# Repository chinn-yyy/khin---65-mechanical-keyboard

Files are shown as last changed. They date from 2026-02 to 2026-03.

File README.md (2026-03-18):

# khin---65-mechanical-keyboard
This keyboard was designed for productivity for the Blueprint club ran by HackClub. It features a 66 key layout with 2 programmable macro keys. I chose the MMD Fairy Linear switches for this project. Not only do they sound amazing, they also match my vibe; transparent. Additionally, I decided to use some random AliExpress screw-in stabilizers that are also, you guessed it, transparent! 

My keyboard isn't just a keyboard with keys. It also features a big, bright, 0.91 inch OLED display that can display the last key you pressed, a fun animation, etc. Not only does it have an OLED it also has 68 addressable LED's. One for each key. These can be any color and any pattern.

On the firmware side of things, my keyboard is being ran by QMK open source firmware on a Raspberry Pi Pico. QMK is specifically designed for keyboards, and not only is it easy to use but it also has tons of features. 

Make sure to look at my Blueprint page to see the journal and the process it took to build this. Here is the link: https://blueprint.hackclub.com/projects/11738

Here are some photos of the finished product:

  Fully Assembled (CAD):
  


  Schematic:


  PCB Editor:


  CAD:
  




[tableConvert.com_irgoez.md](https://github.com/user-attachments/files/25429461/tableConvert.com_irgoez.md)
| Name: | Description: | Price: (each) | Shipping Price: | Quanity: | Manufacturer: | Total Price (with tax + shipping): | URL: |
|---|---|---|---|---|---|---|---|
| Raspberry Pi Pico w/ Headers | 40 pin RP2040 based MCU, the brains for the keyboard. (not the offical one, proceed with caution) | $3.41 | $0.00 | 1 | AliExpress | $3.94 | https://www.aliexpress.us/item/3256805941727857.html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 |
| V2 PCB Mount Screw-in Stabilizers | Keyboard stabilizers, allows the space, shift etc. to not collapse. | $5.27 | $0.00 | 1 | AliExpress | $6.08 | https://www.aliexpress.us/item/3256807050530252.html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 |
| MMD Fairy Switch Linear | Clear keyboard switches, buttons. Pack of 70. | $32.57 | $0.00 | 1 | AliExpress | $37.59 | https://www.aliexpress.us/item/3256805623892710.html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 |
| 1N4148 Switching Diode | Used in the keyboard matrix to prevent ghosting. Pack of 50. | $1.23 | $0.00 | 2 | AliExpress | $2.84 | https://www.aliexpress.us/item/3256806058794623.html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 |
| SK6812 MINI-E RGB | Addressable LED's for the keyboard. Pack of 100. | $6.03 | $0.00 | 1 | AliExpress | $6.96 | https://www.aliexpress.us/item/3256805007401420.html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 |
| 0.91 inch OLED | 0.91 inch, 128x32, SSD1306, I2C, OLED display. (already have) | $1.97 | $0.00 | 1 | AliExpress | $0.00 | https://www.aliexpress.us/item/3256805114690528.html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 |
| Custom PCB | Custom printed circuit board, the foundation. (pack of 5) | $17.60 | $12.97 | 1 | JLCPCB | $33.28 | https://jlcpcb.com/ |
| TOTAL: | | | | | | $91.75 | Link to Google Spreadsheet: https://docs.google.com/spreadsheets/d/17dnJcXFBqe7aWQwjPS5lmQD_NSss1hXRMHxMUS2wsAg/edit?usp=sharing |

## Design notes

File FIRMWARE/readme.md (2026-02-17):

# khin

khin

*65% mechanical keyboard running QMK firmware on a Raspberry Pi Pico with LED's, an OLED display, and 2 macro keys.*

* Keyboard Maintainer: [chinnyyy.](https://github.com/chinnyyy.)
* Hardware Supported: *Raspberry Pi Pico, custom PCB, Durock ice king switches*
* Hardware Availability: *https://github.com/chinn-yyy/khin---65-mechanical-keyboard*

Make example for this keyboard (after setting up your build environment):

    make khin:default

Flashing example for this keyboard:

    make khin:default:flash

See the [build environment setup](https://docs.qmk.fm/#/getting_started_build_tools) and the [make instructions](https://docs.qmk.fm/#/getting_started_make_guide) for more information. Brand new to QMK? Start with our [Complete Newbs Guide](https://docs.qmk.fm/#/newbs).

## Bootloader

Enter the bootloader in 3 ways:

* **Bootmagic reset**: Hold down the key at (0,0) in the matrix (usually the top left key or Escape) and plug in the keyboard
* **Physical reset button**: Briefly press the button on the back of the PCB - some may have pads you must short instead
* **Keycode in layout**: Press the key mapped to `QK_BOOT` if it is available
*

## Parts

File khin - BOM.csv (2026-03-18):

Name: | Description: | Price: (each) | Shipping Price: | Quanity: | Manufacturer: | Total Price (with tax + shipping): | URL:
Raspberry Pi Pico w/ Headers | 40 pin RP2040 based MCU, the brains for the keyboard. (not the offical one, proceed with caution) | $3.41 | $0.00 | 1 | AliExpress | $3.94 | https://www.aliexpress.us/item/3256805941727857.html?mp=1
V2 PCB Mount Screw-in Stabilizers | Keyboard stabilizers, allows the space, shift etc. to not collapse. | $5.27 | $0.00 | 1 | AliExpress | $6.08 | https://www.aliexpress.us/item/3256807050530252.html?mp=1
MMD Fairy Switch Tactile | Clear keyboard switches, buttons. Pack of 70. | $23.23 | $0.00 | 1 | AliExpress | $26.81 | https://www.aliexpress.us/item/3256805876055680.html?curPageLogUid=Gu2HeTS3mv6v
1N4148 Switching Diode | Used in the keyboard matrix to prevent ghosting. Pack of 50. | $1.23 | $0.00 | 2 | AliExpress | $2.84 | https://www.aliexpress.us/item/3256806058794623.html?mp=1
SK6812 MINI-E RGB | Addressable LED's for the keyboard. Pack of 100. | $6.03 | $0.00 | 1 | AliExpress | $6.96 | https://www.aliexpress.us/item/3256805007401420.html?mp=1
0.91 inch OLED | 0.91 inch, 128x32, SSD1306, I2C, OLED display. (already have) | $1.97 | $0.00 | 1 | AliExpress | $2.27 | https://www.aliexpress.us/item/3256805114690528.html?curPageLogUid=xd4wKAHaNW7A
Custom PCB | Custom printed circuit board, the foundation. (pack of 5) | $17.60 | $12.97 | 1 | JLCPCB | $33.28 | https://jlcpcb.com/
TOTAL: |  |  |  |  |  | $82.18 | Link to Google Spreadsheet: https://docs.google.com/spreadsheets/d/17dnJcXFBqe7aWQwjPS5lmQD_NSss1hXRMHxMUS2wsAg/edit?usp=sharing

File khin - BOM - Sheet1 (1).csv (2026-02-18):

Name: | Description: | Price: (each) | Shipping Price: | Quanity: | Manufacturer: | Total Price (with tax + shipping): | URL:
Raspberry Pi Pico w/ Headers | 40 pin RP2040 based MCU, the brains for the keyboard. | $5.00 | $0.00 | 1 | Vilros | $5.00 | https://vilros.com/products/raspberry-pi-pico?variant=41213088825438
GATERON PC Screw in Crystal Stabilizer | Keyboard stabilizers, allows the space, shift etc. to not collapse. | $11.99 | $0.00 | 1 | Amazon | $13.84 | https://www.amazon.com/gp/product/B0BZYK3X1S/ref=ox_sc_act_title_2?smid=A3EQZH47A6MSSO&psc=1
DUROCK Ice King Linear Switches | "Thocky," clear keyboard switches, buttons. Pack of 70. | $36.99 | $0.00 | 1 | Amazon | $42.69 | https://www.amazon.com/gp/product/B0CTH8VFJW/ref=ox_sc_act_image_1?smid=A1G6HFHDKP9H5J&th=1
1N4148 Switching Diode | Used in the keyboard matrix to prevent ghosting. Pack of 50. | $1.23 | $1.99 | 2 | AliExpress | $4.83 | https://www.aliexpress.us/item/3256806058794623.html?mp=1
SK6812 MINI-E RGB | Addressable LED's for the keyboard. Pack of 100. | $6.03 | $0.00* | 1 | AliExpress | $6.96 | https://www.aliexpress.us/item/3256805007401420.html?mp=1
0.91 inch OLED | 0.91 inch, 128x32, SSD1306, I2C, OLED display. (already have) | $1.97 | $0.00 | 1 | AliExpress | $0.00 | https://www.aliexpress.us/item/3256805114690528.html?curPageLogUid=xd4wKAHaNW7A
Custom PCB | Custom printed circuit board, the foundation. (pack of 5) | $17.60 | $12.97 | 1 | JLCPCB | $33.28 | https://jlcpcb.com/
TOTAL: |  |  | *Ships with switching diode |  |  | $106.59 | Link to Google Spreadsheet: https://docs.google.com/spreadsheets/d/17dnJcXFBqe7aWQwjPS5lmQD_NSss1hXRMHxMUS2wsAg/edit?usp=sharing

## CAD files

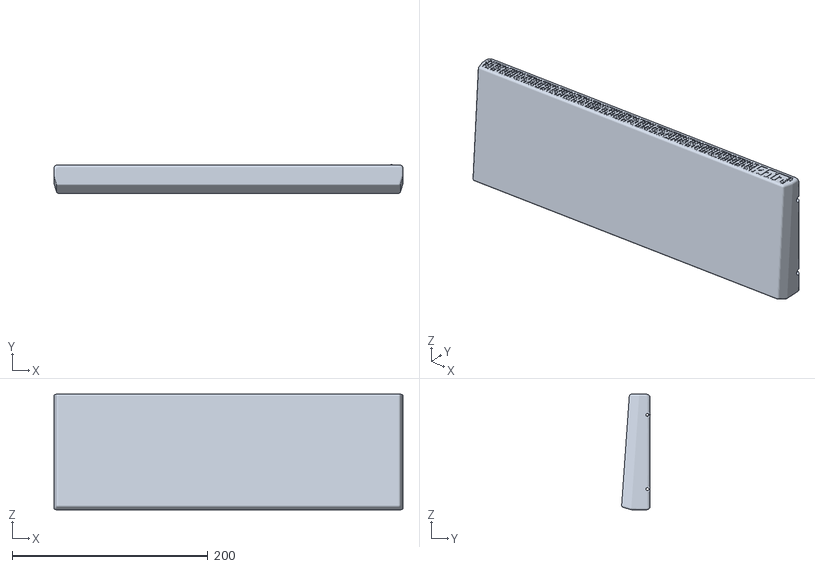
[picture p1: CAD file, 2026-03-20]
CAD/khin - 65% mechanical keyboard BASE.stl
356.5 x 29.4 x 118.0

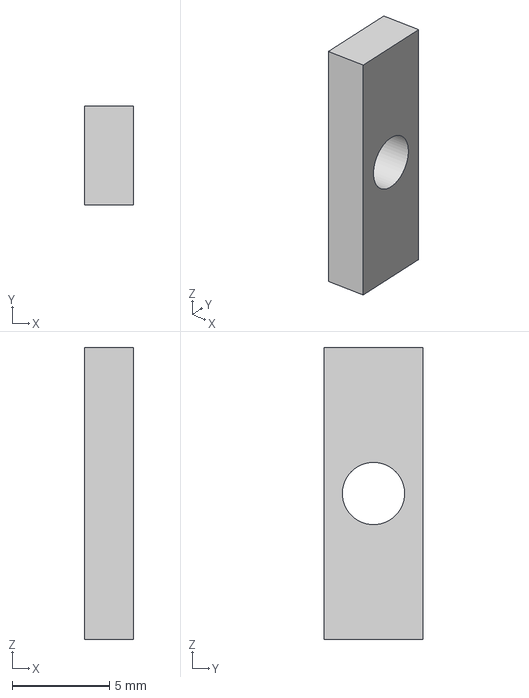
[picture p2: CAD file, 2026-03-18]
CAD/khin - 65% mechanical keyboard CLAMP.step
2.50 x 5.09 x 15.0 mm

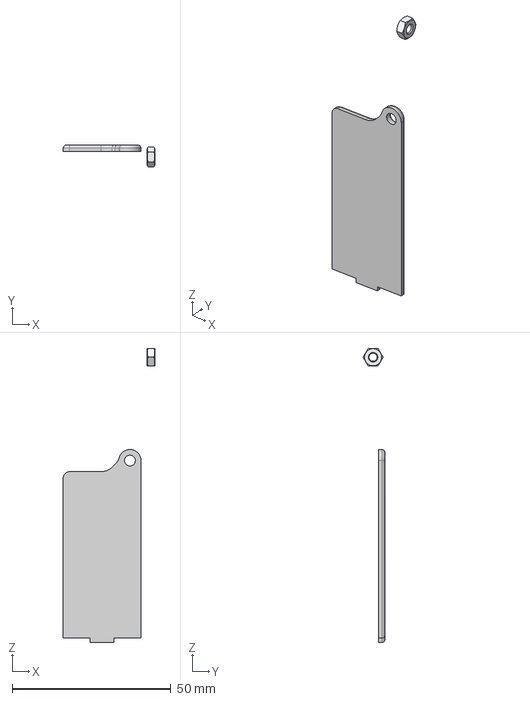
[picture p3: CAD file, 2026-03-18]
CAD/khin - 65% mechanical keyboard PI COVER.step
28.9 x 6.93 x 92.7 mm

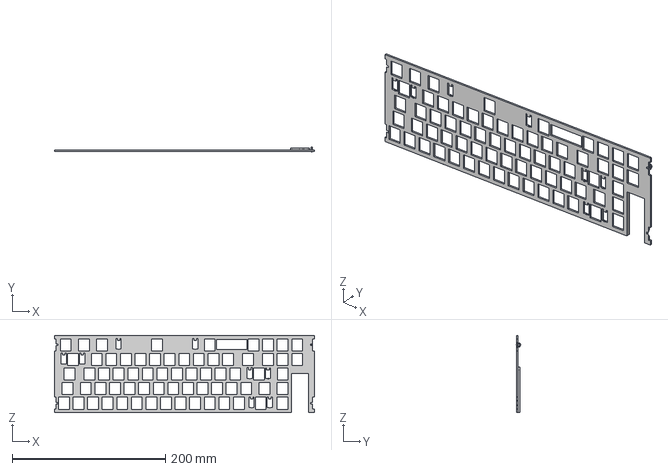
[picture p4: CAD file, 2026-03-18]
CAD/khin - 65% mechanical keyboard COVER.step
339.7 x 6.35 x 101.2 mm

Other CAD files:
CAD/khin - 65% mechanical keyboard CLAMP.stl
CAD/khin - 65% mechanical keyboard COVER.stl
CAD/khin - 65% mechanical keyboard PI COVER.stl
CAD/khin - 65% mechanical keyboardMAIN-FUSION.f3z

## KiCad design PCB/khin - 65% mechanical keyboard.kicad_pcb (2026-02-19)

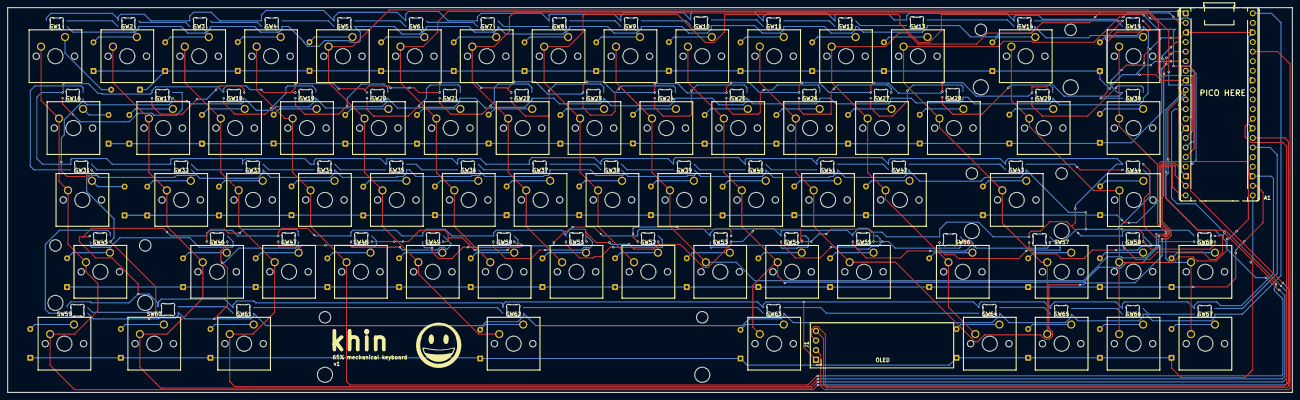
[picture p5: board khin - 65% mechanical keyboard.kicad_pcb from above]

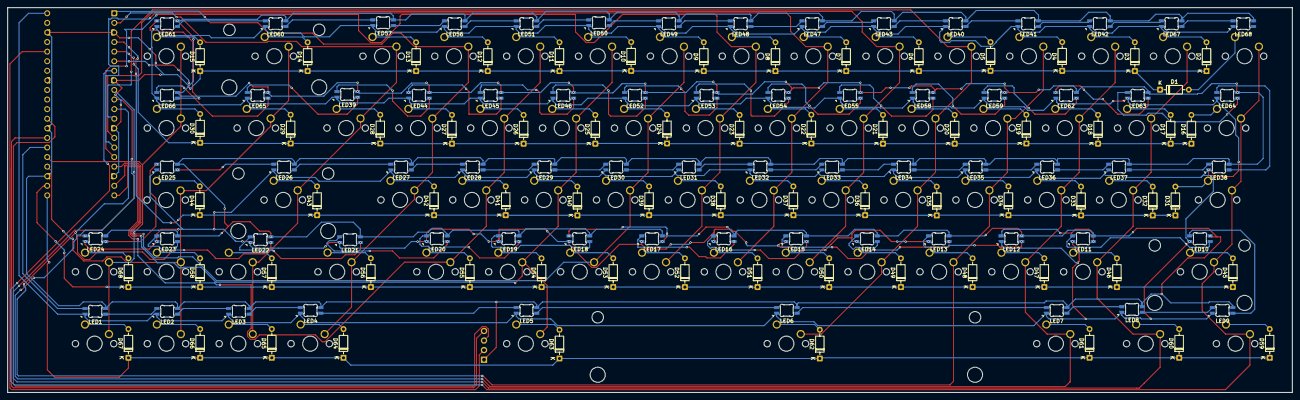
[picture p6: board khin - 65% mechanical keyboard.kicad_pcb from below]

Board: 2 copper layers, 340.5 x 102.0 mm, 206 parts (136 on the bottom side), 161 nets.

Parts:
A1: RaspberryPi_Pico; RaspberryPi_Pico_Common_THT
D1, D2, D3, D4, D5, D6, D7, D8, D9, D10, D11, D12, D13, D14, D15, D16, D17, D18, D19, D20, D21, D22, D23, D24, D25, D26, D27, D28, D29, D30, D31, D32, D33, D34, D35, D36, D37, D38, D39, D40, D41, D42, D43, D44, D45, D46, D47, D48, D49, D50, D51, D52, D53, D54, D55, D56, D57, D58, D59, D60, D61, D62, D63, D64, D65, D66, D67, D68: 1N4148; D_DO-35_SOD27_P7.62mm_Horizontal
J1: Conn_01x04_Pin; OLED_0.91_128x323D
LED1, LED2, LED3, LED4, LED5, LED6, LED7, LED8, LED9, LED10, LED11, LED12, LED13, LED14, LED15, LED16, LED17, LED18, LED19, LED20, LED21, LED22, LED23, LED24, LED25, LED26, LED27, LED28, LED29, LED30, LED31, LED32, LED33, LED34, LED35, LED36, LED37, LED38, LED39, LED40, LED41, LED42, LED43, LED44, LED45, LED46, LED47, LED48, LED49, LED50, LED51, LED52, LED53, LED54, LED55, LED56, LED57, LED58, LED59, LED60, LED61, LED62, LED63, LED64, LED65, LED66, LED67, LED68: MX_SK6812MINI-E; LED_6028R
SW1: SW_Push-ESC; SW_Cherry_MX_1.00u_PCB3D
SW2: SW_Push-1; SW_Cherry_MX_1.00u_PCB3D
SW3: SW_Push-2; SW_Cherry_MX_1.00u_PCB3D
SW4: SW_Push-3; SW_Cherry_MX_1.00u_PCB3D
SW5: SW_Push-4; SW_Cherry_MX_1.00u_PCB3D
SW6: SW_Push-5; SW_Cherry_MX_1.00u_PCB3D
SW7: SW_Push-6; SW_Cherry_MX_1.00u_PCB3D
SW8: SW_Push-7; SW_Cherry_MX_1.00u_PCB3D
SW9: SW_Push-8; SW_Cherry_MX_1.00u_PCB3D
SW10: SW_Push-9; SW_Cherry_MX_1.00u_PCB3D
SW11: SW_Push-0; SW_Cherry_MX_1.00u_PCB3D
SW12: SW_Push-dash; SW_Cherry_MX_1.00u_PCB3D
SW13: SW_Push-=; SW_Cherry_MX_1.00u_PCB3D
SW14: SW_Push-BS; SW_Cherry_MX_2.00u_PCB3D+Stabilizers
SW15: SW_Push-DEL; SW_Cherry_MX_1.00u_PCB3D
SW16: SW_Push-TAB; SW_Cherry_MX_1.50u_PCB3D
SW17: SW_Push-Q; SW_Cherry_MX_1.00u_PCB3D
SW18: SW_Push-W; SW_Cherry_MX_1.00u_PCB3D
SW19: SW_Push-E; SW_Cherry_MX_1.00u_PCB3D
SW20: SW_Push-R; SW_Cherry_MX_1.00u_PCB3D
SW21: SW_Push-T; SW_Cherry_MX_1.00u_PCB3D
SW22: SW_Push-Y; SW_Cherry_MX_1.00u_PCB3D
SW23: SW_Push-U; SW_Cherry_MX_1.00u_PCB3D
SW24: SW_Push-I; SW_Cherry_MX_1.00u_PCB3D
SW25: SW_Push-O; SW_Cherry_MX_1.00u_PCB3D
SW26: SW_Push-P; SW_Cherry_MX_1.00u_PCB3D
SW27: SW_Push-[; SW_Cherry_MX_1.00u_PCB3D
SW28: SW_Push-]; SW_Cherry_MX_1.00u_PCB3D
SW29: SW_Push-\; SW_Cherry_MX_1.50u_PCB3D
SW30: SW_Push-PAS; SW_Cherry_MX_1.00u_PCB3D
SW31: SW_Push-CL; SW_Cherry_MX_1.75u_PCB3D
SW32: SW_Push-A; SW_Cherry_MX_1.00u_PCB3D
SW33: SW_Push-S; SW_Cherry_MX_1.00u_PCB3D
SW34: SW_Push-D; SW_Cherry_MX_1.00u_PCB3D
SW35: SW_Push-F; SW_Cherry_MX_1.00u_PCB3D
SW36: SW_Push-G; SW_Cherry_MX_1.00u_PCB3D
SW37: SW_Push-H; SW_Cherry_MX_1.00u_PCB3D
SW38: SW_Push-J; SW_Cherry_MX_1.00u_PCB3D
SW39: SW_Push-K; SW_Cherry_MX_1.00u_PCB3D
SW40: SW_Push-L; SW_Cherry_MX_1.00u_PCB3D
SW41: SW_Push-;; SW_Cherry_MX_1.00u_PCB3D
SW42: SW_Push-'; SW_Cherry_MX_1.00u_PCB3D
SW43: SW_Push-EN; SW_Cherry_MX_2.25u_PCB3D+Stabilizer
SW44: SW_Push-LM; SW_Cherry_MX_1.00u_PCB3D
SW45: SW_Push-LSH; SW_Cherry_MX_2.25u_PCB3D+Stabilizer
SW46: SW_Push-Z; SW_Cherry_MX_1.00u_PCB3D
SW47: SW_Push-X; SW_Cherry_MX_1.00u_PCB3D
SW48: SW_Push-C; SW_Cherry_MX_1.00u_PCB3D
SW49: SW_Push-V; SW_Cherry_MX_1.00u_PCB3D
SW50: SW_Push-B; SW_Cherry_MX_1.00u_PCB3D
SW51: SW_Push-N; SW_Cherry_MX_1.00u_PCB3D
SW52: SW_Push-M; SW_Cherry_MX_1.00u_PCB3D
SW53: SW_Push-,; SW_Cherry_MX_1.00u_PCB3D
SW54: SW_Push-.; SW_Cherry_MX_1.00u_PCB3D
SW55: SW_Push-/; SW_Cherry_MX_1.00u_PCB3D
SW56: SW_Push-RSH; SW_Cherry_MX_1.75u_PCB3D
SW57: SW_Push-UPA; SW_Cherry_MX_1.00u_PCB3D
SW58: SW_Push-MODE; SW_Cherry_MX_1.00u_PCB3D
SW59: SW_Push-LCTL; SW_Cherry_MX_1.25u_PCB3D
SW60: SW_Push-WIN; SW_Cherry_MX_1.25u_PCB3D
SW61: SW_Push-LALT; SW_Cherry_MX_1.25u_PCB3D
SW62: SW_Push-SP; SW_Cherry_MX_6.25u_PCB3D
SW63: SW_Push-RCTL; SW_Cherry_MX_1.00u_PCB3D
SW64: SW_Push-LA; SW_Cherry_MX_1.00u_PCB3D
SW65: SW_Push-DA; SW_Cherry_MX_1.00u_PCB3D
SW66: SW_Push-RA; SW_Cherry_MX_1.00u_PCB3D
SW67: SW_Push-M2; SW_Cherry_MX_1.00u_PCB3D
SW68: SW_Push-M1; SW_Cherry_MX_1.00u_PCB3D

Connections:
+3V3: A1.36 (3V3), J1.2
+5V: A1.40 (VBUS), LED1.4 (VSS), LED2.4 (VSS), LED3.4 (VSS), LED4.4 (VSS), LED5.4 (VSS), LED6.4 (VSS), LED7.4 (VSS), LED8.4 (VSS), LED9.4 (VSS), LED10.4 (VSS), LED11.4 (VSS), LED12.4 (VSS), LED13.4 (VSS), LED14.4 (VSS), LED15.4 (VSS), LED16.4 (VSS), LED17.4 (VSS), LED18.4 (VSS), LED19.4 (VSS), LED20.4 (VSS), LED21.4 (VSS), LED22.4 (VSS), LED23.4 (VSS), LED24.4 (VSS), LED25.4 (VSS), LED26.4 (VSS), LED27.4 (VSS), LED28.4 (VSS), LED29.4 (VSS), LED30.4 (VSS), LED31.4 (VSS), LED32.4 (VSS), LED33.4 (VSS), LED34.4 (VSS), LED35.4 (VSS), LED36.4 (VSS), LED37.4 (VSS), LED38.4 (VSS), LED39.4 (VSS), LED40.4 (VSS), LED41.4 (VSS), LED42.4 (VSS), LED43.4 (VSS), LED44.4 (VSS), LED45.4 (VSS), LED46.4 (VSS), LED47.4 (VSS), LED48.4 (VSS), LED49.4 (VSS), LED50.4 (VSS), LED51.4 (VSS), LED52.4 (VSS), LED53.4 (VSS), LED54.4 (VSS), LED55.4 (VSS), LED56.4 (VSS), LED57.4 (VSS), LED58.4 (VSS), LED59.4 (VSS), LED60.4 (VSS), LED61.4 (VSS), LED62.4 (VSS), LED63.4 (VSS), LED64.4 (VSS), LED65.4 (VSS), LED66.4 (VSS), LED67.4 (VSS), LED68.4 (VSS)
Col 0: A1.7 (GPIO5), SW1.2, SW16.2, SW31.2, SW45.2, SW59.2
Col 1: A1.9 (GPIO6), SW2.2, SW17.2, SW32.2, SW46.2, SW60.2
Col 2: A1.10 (GPIO7), SW3.2, SW18.2, SW33.2, SW47.2, SW61.2
Col 3: A1.11 (GPIO8), SW4.2, SW19.2, SW34.2, SW48.2
Col 4: A1.12 (GPIO9), SW5.2, SW20.2, SW35.2, SW49.2, SW62.2
Col 5: A1.14 (GPIO10), SW6.2, SW21.2, SW36.2, SW50.2
Col 6: A1.15 (GPIO11), SW7.2, SW22.2, SW37.2, SW51.2
Col 7: A1.16 (GPIO12), SW8.2, SW23.2, SW38.2, SW52.2
Col 8: A1.17 (GPIO13), SW9.2, SW24.2, SW39.2, SW53.2
Col 9: A1.19 (GPIO14), SW10.2, SW25.2, SW40.2, SW54.2, SW63.2
Col 10: A1.20 (GPIO15), SW11.2, SW26.2, SW41.2, SW55.2
Col 11: A1.1 (GPIO0), SW12.2, SW27.2, SW42.2, SW56.2, SW64.2
Col 12: A1.2 (GPIO1), SW13.2, SW28.2, SW43.2, SW57.2, SW65.2
Col 13: A1.24 (GPIO18), SW14.2, SW29.2, SW44.2, SW58.2, SW66.2
Col 14: A1.25 (GPIO19), SW15.2, SW30.2, SW67.2, SW68.2
GND: A1.3 (GND), A1.8 (GND), A1.13 (GND), A1.18 (GND), A1.23 (GND), A1.28 (GND), A1.38 (GND), J1.1, LED1.1 (VDD), LED2.1 (VDD), LED3.1 (VDD), LED4.1 (VDD), LED5.1 (VDD), LED6.1 (VDD), LED7.1 (VDD), LED8.1 (VDD), LED9.1 (VDD), LED10.1 (VDD), LED11.1 (VDD), LED12.1 (VDD), LED13.1 (VDD), LED14.1 (VDD), LED15.1 (VDD), LED16.1 (VDD), LED17.1 (VDD), LED18.1 (VDD), LED19.1 (VDD), LED20.1 (VDD), LED21.1 (VDD), LED22.1 (VDD), LED23.1 (VDD), LED24.1 (VDD), LED25.1 (VDD), LED26.1 (VDD), LED27.1 (VDD), LED28.1 (VDD), LED29.1 (VDD), LED30.1 (VDD), LED31.1 (VDD), LED32.1 (VDD), LED33.1 (VDD), LED34.1 (VDD), LED35.1 (VDD), LED36.1 (VDD), LED37.1 (VDD), LED38.1 (VDD), LED39.1 (VDD), LED40.1 (VDD), LED41.1 (VDD), LED42.1 (VDD), LED43.1 (VDD), LED44.1 (VDD), LED45.1 (VDD), LED46.1 (VDD), LED47.1 (VDD), LED48.1 (VDD), LED49.1 (VDD), LED50.1 (VDD), LED51.1 (VDD), LED52.1 (VDD), LED53.1 (VDD), LED54.1 (VDD), LED55.1 (VDD), LED56.1 (VDD), LED57.1 (VDD), LED58.1 (VDD), LED59.1 (VDD), LED60.1 (VDD), LED61.1 (VDD), LED62.1 (VDD), LED63.1 (VDD), LED64.1 (VDD), LED65.1 (VDD), LED66.1 (VDD), LED67.1 (VDD), LED68.1 (VDD)
LED: A1.26 (GPIO20), LED1.3 (DIN)
LED ROW 1 TO ROW 2: LED12.2 (DOUT), LED13.3 (DIN)
LED ROW 2 TO ROW 3: LED25.2 (DOUT), LED26.3 (DIN)
LED ROW 3 TO ROW 4: LED38.2 (DOUT), LED64.3 (DIN)
LED ROW 4 TO ROW 5: LED39.2 (DOUT), LED65.3 (DIN)
unnamed: D1.2 (A), SW1.1
unnamed: D2.2 (A), SW2.1
unnamed: D3.2 (A), SW3.1
unnamed: D4.2 (A), SW4.1
unnamed: D5.2 (A), SW5.1
unnamed: D6.2 (A), SW6.1
unnamed: D7.2 (A), SW7.1
unnamed: D8.2 (A), SW8.1
unnamed: D9.2 (A), SW9.1
unnamed: D10.2 (A), SW10.1
unnamed: D11.2 (A), SW11.1
unnamed: D12.2 (A), SW12.1
unnamed: D13.2 (A), SW13.1
unnamed: D14.2 (A), SW14.1
unnamed: D15.2 (A), SW15.1
unnamed: D16.2 (A), SW16.1
unnamed: D17.2 (A), SW17.1
unnamed: D18.2 (A), SW18.1
unnamed: D19.2 (A), SW19.1
unnamed: D20.2 (A), SW20.1
unnamed: D21.2 (A), SW21.1
unnamed: D22.2 (A), SW22.1
unnamed: D23.2 (A), SW23.1
unnamed: D24.2 (A), SW24.1
unnamed: D25.2 (A), SW25.1
unnamed: D26.2 (A), SW26.1
unnamed: D27.2 (A), SW27.1
unnamed: D28.2 (A), SW28.1
unnamed: D29.2 (A), SW29.1
unnamed: D30.2 (A), SW30.1
unnamed: D31.2 (A), SW31.1
unnamed: D32.2 (A), SW32.1
unnamed: D33.2 (A), SW33.1
unnamed: D34.2 (A), SW34.1
unnamed: D35.2 (A), SW35.1
unnamed: D36.2 (A), SW36.1
unnamed: D37.2 (A), SW37.1
unnamed: D38.2 (A), SW38.1
unnamed: D39.2 (A), SW39.1
unnamed: D40.2 (A), SW40.1
unnamed: D41.2 (A), SW41.1
unnamed: D42.2 (A), SW42.1
unnamed: D43.2 (A), SW43.1
unnamed: D44.2 (A), SW44.1
unnamed: D45.2 (A), SW45.1
unnamed: D46.2 (A), SW46.1
unnamed: D47.2 (A), SW47.1
unnamed: D48.2 (A), SW48.1
unnamed: D49.2 (A), SW49.1
unnamed: D50.2 (A), SW50.1
unnamed: D51.2 (A), SW51.1
unnamed: D52.2 (A), SW52.1
unnamed: D53.2 (A), SW53.1
unnamed: D54.2 (A), SW54.1
unnamed: D55.2 (A), SW55.1
unnamed: D56.2 (A), SW56.1
unnamed: D57.2 (A), SW57.1
unnamed: D58.2 (A), SW58.1
unnamed: D59.2 (A), SW59.1
unnamed: D60.2 (A), SW60.1
unnamed: D61.2 (A), SW61.1
unnamed: D62.2 (A), SW62.1
unnamed: D63.2 (A), SW63.1
unnamed: D64.2 (A), SW64.1
unnamed: D65.2 (A), SW65.1
unnamed: D66.2 (A), SW66.1
unnamed: D67.2 (A), SW67.1
unnamed: D68.2 (A), SW68.1
unnamed: LED1.2 (DOUT), LED2.3 (DIN)
unnamed: LED2.2 (DOUT), LED3.3 (DIN)
unnamed: LED3.2 (DOUT), LED4.3 (DIN)
unnamed: LED4.2 (DOUT), LED5.3 (DIN)
unnamed: LED5.2 (DOUT), LED6.3 (DIN)
unnamed: LED6.2 (DOUT), LED7.3 (DIN)
unnamed: LED7.2 (DOUT), LED8.3 (DIN)
unnamed: LED8.2 (DOUT), LED9.3 (DIN)
unnamed: LED9.2 (DOUT), LED10.3 (DIN)
unnamed: LED10.2 (DOUT), LED11.3 (DIN)
unnamed: LED11.2 (DOUT), LED12.3 (DIN)
unnamed: LED13.2 (DOUT), LED14.3 (DIN)
unnamed: LED14.2 (DOUT), LED15.3 (DIN)
unnamed: LED15.2 (DOUT), LED16.3 (DIN)
unnamed: LED16.2 (DOUT), LED17.3 (DIN)
unnamed: LED17.2 (DOUT), LED18.3 (DIN)
unnamed: LED18.2 (DOUT), LED19.3 (DIN)
unnamed: LED19.2 (DOUT), LED20.3 (DIN)
unnamed: LED20.2 (DOUT), LED21.3 (DIN)
unnamed: LED21.2 (DOUT), LED22.3 (DIN)
unnamed: LED22.2 (DOUT), LED23.3 (DIN)
unnamed: LED23.2 (DOUT), LED24.3 (DIN)
unnamed: LED24.2 (DOUT), LED25.3 (DIN)
unnamed: LED26.2 (DOUT), LED27.3 (DIN)
unnamed: LED27.2 (DOUT), LED28.3 (DIN)
unnamed: LED28.2 (DOUT), LED29.3 (DIN)
unnamed: LED29.2 (DOUT), LED30.3 (DIN)
unnamed: LED30.2 (DOUT), LED31.3 (DIN)
unnamed: LED31.2 (DOUT), LED32.3 (DIN)
unnamed: LED32.2 (DOUT), LED33.3 (DIN)
unnamed: LED33.2 (DOUT), LED34.3 (DIN)
unnamed: LED34.2 (DOUT), LED35.3 (DIN)
unnamed: LED35.2 (DOUT), LED36.3 (DIN)
unnamed: LED36.2 (DOUT), LED37.3 (DIN)
unnamed: LED37.2 (DOUT), LED38.3 (DIN)
unnamed: LED39.3 (DIN), LED44.2 (DOUT)
unnamed: LED40.3 (DIN), LED43.2 (DOUT)
unnamed: LED40.2 (DOUT), LED41.3 (DIN)
unnamed: LED41.2 (DOUT), LED42.3 (DIN)
unnamed: LED42.2 (DOUT), LED67.3 (DIN)
unnamed: LED43.3 (DIN), LED47.2 (DOUT)
unnamed: LED44.3 (DIN), LED45.2 (DOUT)
unnamed: LED45.3 (DIN), LED46.2 (DOUT)
unnamed: LED46.3 (DIN), LED52.2 (DOUT)
unnamed: LED47.3 (DIN), LED48.2 (DOUT)
unnamed: LED48.3 (DIN), LED49.2 (DOUT)
unnamed: LED49.3 (DIN), LED50.2 (DOUT)
unnamed: LED50.3 (DIN), LED51.2 (DOUT)
unnamed: LED51.3 (DIN), LED56.2 (DOUT)
unnamed: LED52.3 (DIN), LED53.2 (DOUT)
unnamed: LED53.3 (DIN), LED54.2 (DOUT)
unnamed: LED54.3 (DIN), LED55.2 (DOUT)
unnamed: LED55.3 (DIN), LED58.2 (DOUT)
unnamed: LED56.3 (DIN), LED57.2 (DOUT)
unnamed: LED57.3 (DIN), LED60.2 (DOUT)
unnamed: LED58.3 (DIN), LED59.2 (DOUT)
unnamed: LED59.3 (DIN), LED62.2 (DOUT)
unnamed: LED60.3 (DIN), LED61.2 (DOUT)
unnamed: LED61.3 (DIN), LED66.2 (DOUT)
unnamed: LED62.3 (DIN), LED63.2 (DOUT)
unnamed: LED63.3 (DIN), LED64.2 (DOUT)
unnamed: LED65.2 (DOUT), LED66.3 (DIN)
unnamed: LED67.2 (DOUT), LED68.3 (DIN)
Row 0: A1.6 (GPIO4), D1.1 (K), D2.1 (K), D3.1 (K), D4.1 (K), D5.1 (K), D6.1 (K), D7.1 (K), D8.1 (K), D9.1 (K), D10.1 (K), D11.1 (K), D12.1 (K), D13.1 (K), D14.1 (K), D15.1 (K)
Row 1: A1.5 (GPIO3), D16.1 (K), D17.1 (K), D18.1 (K), D19.1 (K), D20.1 (K), D21.1 (K), D22.1 (K), D23.1 (K), D24.1 (K), D25.1 (K), D26.1 (K), D27.1 (K), D28.1 (K), D29.1 (K), D30.1 (K)
Row 2: A1.4 (GPIO2), D31.1 (K), D32.1 (K), D33.1 (K), D34.1 (K), D35.1 (K), D36.1 (K), D37.1 (K), D38.1 (K), D39.1 (K), D40.1 (K), D41.1 (K), D42.1 (K), D43.1 (K), D44.1 (K)
Row 3: A1.22 (GPIO17), D45.1 (K), D46.1 (K), D47.1 (K), D48.1 (K), D49.1 (K), D50.1 (K), D51.1 (K), D52.1 (K), D53.1 (K), D54.1 (K), D55.1 (K), D56.1 (K), D57.1 (K), D58.1 (K), D68.1 (K)
Row 4: A1.21 (GPIO16), D59.1 (K), D60.1 (K), D61.1 (K), D62.1 (K), D63.1 (K), D64.1 (K), D65.1 (K), D66.1 (K), D67.1 (K)
SCL - OLED 1: A1.27 (GPIO21), J1.4
SDA - OLED 2: A1.29 (GPIO22), J1.3

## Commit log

2026-02-10 Update and rename khin - BOM - Sheet1.csv to COMMA SEPERATED VALUES BOM
2026-02-17 Rename khin - 65% mechanical keyboard.f3z to khin - 65% mechanical keyboard (fully assembled).f3z
    [khin - 65% mechanical keyboard (fully assembled).f3z]
2026-02-18 Update and rename khin - BOM - Sheet1 (1).csv to khin - BOM.csv
    [khin - BOM.csv]
2026-02-19 Update khin - BOM.csv
    [khin - BOM.csv]
2026-03-18 Rename khin - 65% mechanical keyboardv2.step to khin - 65% mechanical keyboard MAIN.step
    [khin - 65% mechanical keyboard MAIN.step]
2026-03-18 Rename khin - 65% mechanical keyboardv2-fusion.f3z to khin - 65% mechanical keyboardMAIN-FUSION.f3z
    [khin - 65% mechanical keyboardMAIN-FUSION.f3z]
